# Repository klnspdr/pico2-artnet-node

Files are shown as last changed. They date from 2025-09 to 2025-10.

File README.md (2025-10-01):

# pico2-artnet-node

## Upload to JLCPCB
To generate files for uploading to JLCPCB, the plugin ["Fabrication Toolkit"](https://github.com/bennymeg/Fabrication-Toolkit) is used. It generates Gerber and BOM/Pick'n'Places files. Upload the `.zip` in `production/` as the Gerber file and in PCBA upload `bom.csv`  and `positions.csv`

## Estimated Price

PCB + SMD Components: 8.146$ / board
Missing Components:
    - 4x XLR Connectors (~1.40€ / piece)
    - 1x WizNet W5500-EVB-PICO2 (~12€ / piece)
    - 1x B0505S (~1.05$ / piece)
    - 1x WIZPoE Module (~8€ / piece)
    - 2x 1x20 2.54mm Pinsocket THT Vertical (~0.15$ / piece)
    - 3x 1x4 2.54mm Pinsocket THT Vertical (~0.05$ / piece)

=> Overall cost per board (without shipping): ~20€ / ~28€ (without/with PoE)

## Possible other features / TODOs
- [x] LED showing powered state
- [x] Pinheader for I2C
- [x] Levelshifter for WS2812 etc driving (maybe with separate power input?)
- [ ] Test points
- [x] Silkscreen
- [ ] Mounting Holes
- [ ] JLC Ordering Number / mounting holes for PCBA

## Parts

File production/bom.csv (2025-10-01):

Designator | Footprint | Quantity | Value | LCSC Part #
C1, C11, C14, C17, C20, C4, C5, C8 | 0603 | 8 | 10u | C19702
C10, C12, C13, C15, C16, C18, C19, C6, C7, C9 | 0603 | 10 | 0.1u | C14663
C2, C3 | 1206 | 2 | 100u | C15008
D1, D2, D3 | SOD-323_L1.7-W1.3-LS2.6-RD-1 | 3 | B0520WS | C7502696
D10, D4, D6, D8 | 0805 | 4 | YELLOW | C2296
D11, D5, D7, D9 | 0805 | 4 | RED | C84256
J1 | USB-C-SMD_YPE-C-6PWTL-10-0108 | 1 | USB_C_Receptacle_PowerOnly_6P | C30167331
R1, R2 | 0603 | 2 | 5.1k
R10, R15, R20, R5 | 0603 | 4 | 120R
R11, R14, R16, R19, R21, R4, R6, R9 | 0603 | 8 | 510R
R12, R13, R17, R18, R22, R3, R7, R8 | 0603 | 8 | 56
U3 | SOT-223-3_TabPin2 | 1 | AMS1117-3.3 | C6186
U5, U6, U7, U8 | SOIC-16_L10.3-W7.5-P1.27-LS10.3-BL | 4 | ISO1410BDWR | C2671027

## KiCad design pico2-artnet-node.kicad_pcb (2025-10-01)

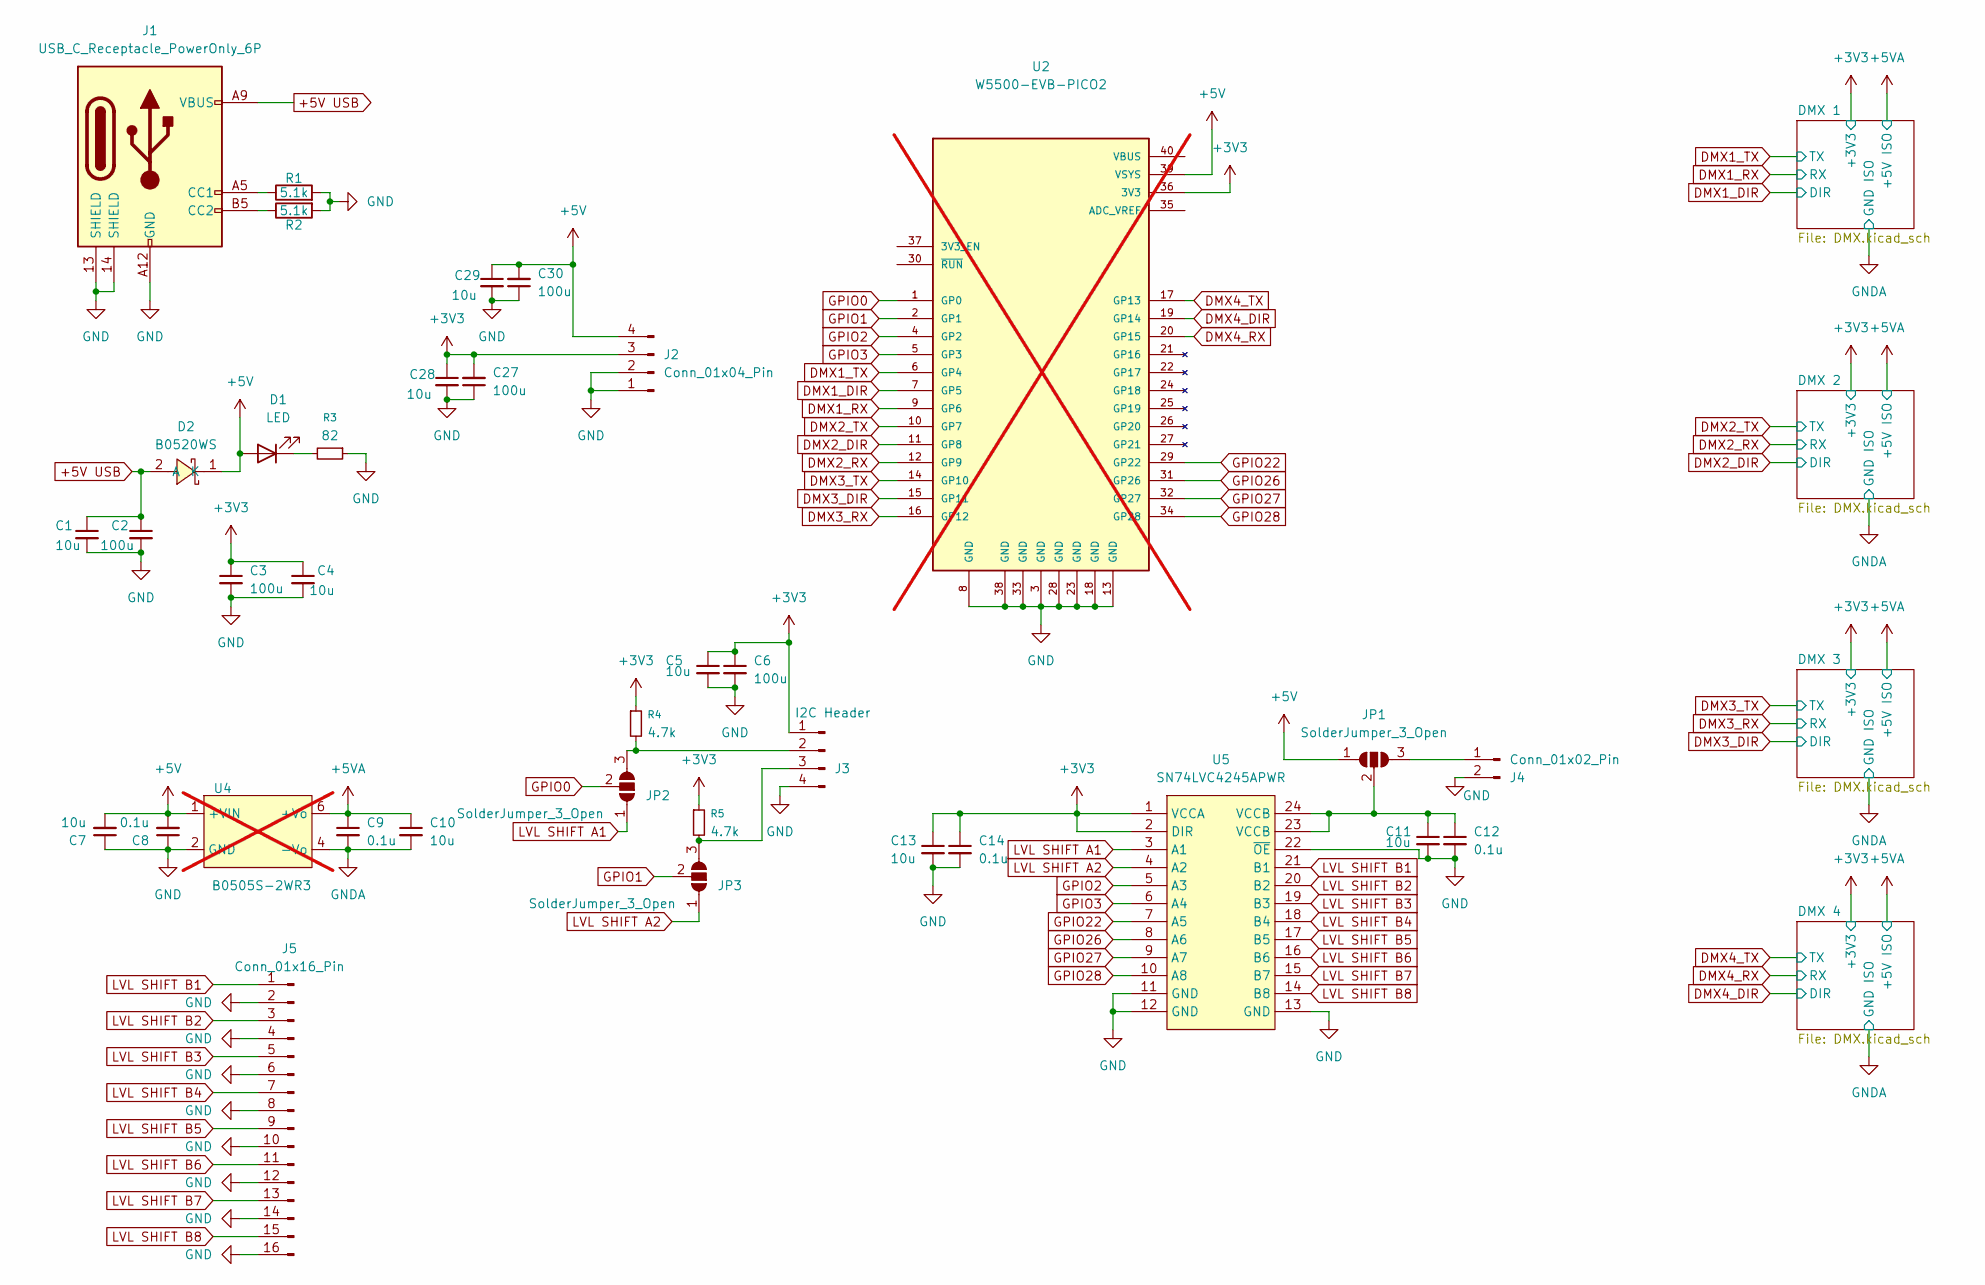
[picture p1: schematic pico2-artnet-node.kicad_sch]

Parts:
C1, C4, C5, C7, C10, C11, C13, C28, C29: 10u; C_0603_1608Metric; LCSC Part C19702
C2, C3, C6, C27, C30: 100u; C_1206_3216Metric; LCSC Part C15008
C8, C9, C12, C14: 0.1u; C_0603_1608Metric; LCSC Part C14663
D1: LED; LED_0805_2012Metric; LCSC Part C2297
D2: B0520WS; SOD-323_L1.7-W1.3-LS2.6-RD-1; LCSC Part C7502696
J1: USB_C_Receptacle_PowerOnly_6P; USB-C-SMD_YPE-C-6PWTL-10-0108_Board-overhang; LCSC Part C30167331
J2: Conn_01x04_Pin; FanPinHeader_1x04_P2.54mm_Vertical
J3: I2C Header; FanPinHeader_1x04_P2.54mm_Vertical
J4: Conn_01x02_Pin; PinSocket_1x02_P2.54mm_Vertical
J5: Conn_01x16_Pin; PinSocket_1x16_P2.54mm_Vertical
JP1, JP2, JP3: SolderJumper_3_Open; PinHeader_1x03_P2.54mm_Vertical
R1, R2: 5.1k; R_0603_1608Metric
R3: 82; R_0603_1608Metric
R4, R5: 4.7k; R_0603_1608Metric
U2: W5500-EVB-PICO2; MODULE_W5500-EVB-PICO2; PARTREV 2022-01-28; not fitted
U4: B0505S-2WR3; PWRM-TH_BXXXXS-2WR3; LCSC Part C5369473; not fitted
U5: SN74LVC4245APWR; TSSOP-24_L7.8-W4.4-P0.65-LS6.4-BL; LCSC Part C7859

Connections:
+3V3: C3.1, C4.1, C5.1, C6.1, C13.1, C14.1, C27.2, C28.1, J2.3, J3.1, R4.1, R5.1, U2.36 (3V3), U5.1 (VCCA), U5.2 (DIR); also elsewhere on the board
+5V: C7.2, C8.2, C29.1, C30.2, D1.2 (A), D2.1 (K), J2.4, JP1.1 (A), U2.39 (VSYS), U4.1 (+VIN)
+5V USB: C1.1, C2.1, D2.2 (A), J1.A9 (VBUS), J1.B9 (VBUS)
+5VA: C9.1, C10.1, U4.6 (+Vo); also elsewhere on the board
DMX1_DIR: U2.7 (GP5); also elsewhere on the board
DMX1_RX: U2.9 (GP6); also elsewhere on the board
DMX1_TX: U2.6 (GP4); also elsewhere on the board
DMX2_DIR: U2.11 (GP8); also elsewhere on the board
DMX2_RX: U2.12 (GP9); also elsewhere on the board
DMX2_TX: U2.10 (GP7); also elsewhere on the board
DMX3_DIR: U2.15 (GP11); also elsewhere on the board
DMX3_RX: U2.16 (GP12); also elsewhere on the board
DMX3_TX: U2.14 (GP10); also elsewhere on the board
DMX4_DIR: U2.19 (GP14); also elsewhere on the board
DMX4_RX: U2.20 (GP15); also elsewhere on the board
DMX4_TX: U2.17 (GP13); also elsewhere on the board
GND: C1.2, C2.2, C3.2, C4.2, C5.2, C6.2, C7.1, C8.1, C11.2, C12.2, C13.2, C14.2, C27.1, C28.2, C29.2, C30.1, J1.13 (SHIELD), J1.14 (SHIELD), J1.A12 (GND), J1.B12 (GND), J2.1, J2.2, J3.4, J4.2, J5.2, J5.4, J5.6, J5.8, J5.10, J5.12, J5.14, J5.16, R1.2, R2.2, R3.1, U2.3 (GND), U2.8 (GND), U2.13 (GND), U2.18 (GND), U2.23 (GND), U2.28 (GND), U2.33 (GND), U2.38 (GND), U4.2 (GND), U5.11 (GND), U5.12 (GND), U5.13 (GND), U5.22 (~OE); also elsewhere on the board
GNDA: C9.2, C10.2, U4.4 (-Vo); also elsewhere on the board
GPIO0: JP2.2 (C), U2.1 (GP0)
GPIO1: JP3.2 (C), U2.2 (GP1)
GPIO2: U2.4 (GP2), U5.5 (A3)
GPIO3: U2.5 (GP3), U5.6 (A4)
GPIO22: U2.29 (GP22), U5.7 (A5)
GPIO26: U2.31 (GP26), U5.8 (A6)
GPIO27: U2.32 (GP27), U5.9 (A7)
GPIO28: U2.34 (GP28), U5.10 (A8)
LVL SHIFT A1: JP2.1 (A), U5.3 (A1)
LVL SHIFT A2: JP3.1 (A), U5.4 (A2)
LVL SHIFT B1: J5.1, U5.21 (B1)
LVL SHIFT B2: J5.3, U5.20 (B2)
LVL SHIFT B3: J5.5, U5.19 (B3)
LVL SHIFT B4: J5.7, U5.18 (B4)
LVL SHIFT B5: J5.9, U5.17 (B5)
LVL SHIFT B6: J5.11, U5.16 (B6)
LVL SHIFT B7: J5.13, U5.15 (B7)
LVL SHIFT B8: J5.15, U5.14 (B8)
unnamed: D1.1 (K), R3.2
unnamed: J1.A5 (CC1), R1.1
unnamed: J1.B5 (CC2), R2.1
unnamed: J3.2, JP2.3 (B), R4.2
unnamed: J3.3, JP3.3 (B), R5.2
unnamed: J4.1, JP1.3 (B)
unnamed: C11.1, C12.1, JP1.2 (C), U5.23 (VCCB), U5.24 (VCCB)

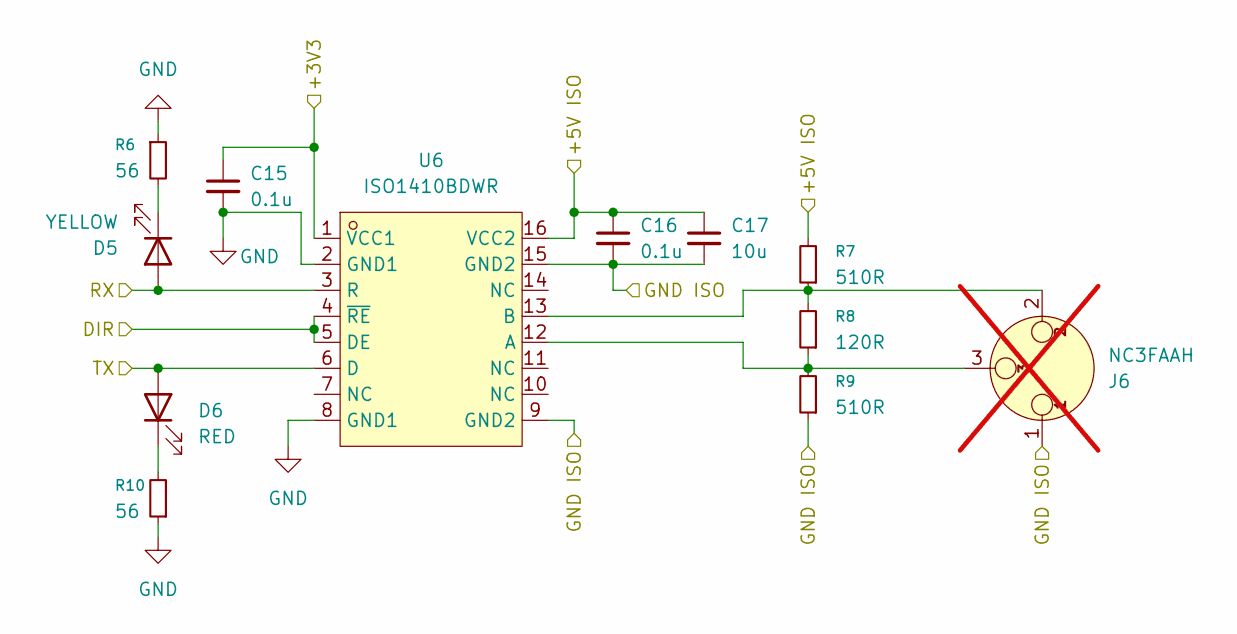
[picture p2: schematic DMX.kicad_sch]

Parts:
C15, C16: 0.1u; C_0603_1608Metric; LCSC Part C14663
C17: 10u; C_0603_1608Metric; LCSC Part C19702
D5: YELLOW; LED_0805_2012Metric; LCSC Part C2296
D6: RED; LED_0805_2012Metric; LCSC Part C84256
J6: NC3FAAH; Jack_XLR_Neutrik_NC3FAAH_Horizontal_Board-Overhang; LCSC Part C368521; not fitted
R6, R10: 56; R_0603_1608Metric
R7, R9: 510R; R_0603_1608Metric
R8: 120R; R_0603_1608Metric
U6: ISO1410BDWR; SOIC-16_L10.3-W7.5-P1.27-LS10.3-BL; LCSC Part C2671027

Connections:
+3V3: C15.1, U6.1 (VCC1); also elsewhere on the board
+5VA: C16.1, C17.1, R7.2, U6.16 (VCC2); also elsewhere on the board
DMX1_DIR: U6.4 (~RE), U6.5 (DE); also elsewhere on the board
DMX1_RX: D5.2 (A), U6.3 (R); also elsewhere on the board
DMX1_TX: D6.2 (A), U6.6 (D); also elsewhere on the board
GND: C15.2, R6.1, R10.1, U6.2 (GND1), U6.8 (GND1); also elsewhere on the board
GNDA: C16.2, C17.2, J6.1, R9.1, U6.9 (GND2), U6.15 (GND2); also elsewhere on the board
unnamed: D5.1 (K), R6.2
unnamed: D6.1 (K), R10.2
unnamed: J6.3, R8.1, R9.2, U6.12 (A)
unnamed: J6.2, R7.1, R8.2, U6.13 (B)

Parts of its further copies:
C18, C19, C21, C22, C24, C25: 0.1u; C_0603_1608Metric; LCSC Part C14663
C20, C23, C26: 10u; C_0603_1608Metric; LCSC Part C19702
D7, D9, D11: YELLOW; LED_0805_2012Metric; LCSC Part C2296
D8, D10, D12: RED; LED_0805_2012Metric; LCSC Part C84256
J7, J8, J9: NC3FAAH; Jack_XLR_Neutrik_NC3FAAH_Horizontal_Board-Overhang; LCSC Part C368521; not fitted
R11, R15, R16, R20, R21, R25: 56; R_0603_1608Metric
R12, R14, R17, R19, R22, R24: 510R; R_0603_1608Metric
R13, R18, R23: 120R; R_0603_1608Metric
U7, U8, U9: ISO1410BDWR; SOIC-16_L10.3-W7.5-P1.27-LS10.3-BL; LCSC Part C2671027

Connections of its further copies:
+3V3: C18.1, C21.1, C24.1, U7.1 (VCC1), U8.1 (VCC1), U9.1 (VCC1); also elsewhere on the board
+5VA: C19.1, C20.1, C22.1, C23.1, C25.1, C26.1, R12.2, R17.2, R22.2, U7.16 (VCC2), U8.16 (VCC2), U9.16 (VCC2); also elsewhere on the board
DMX2_DIR: U7.4 (~RE), U7.5 (DE); also elsewhere on the board
DMX2_RX: D7.2 (A), U7.3 (R); also elsewhere on the board
DMX2_TX: D8.2 (A), U7.6 (D); also elsewhere on the board
DMX3_DIR: U8.4 (~RE), U8.5 (DE); also elsewhere on the board
DMX3_RX: D9.2 (A), U8.3 (R); also elsewhere on the board
DMX3_TX: D10.2 (A), U8.6 (D); also elsewhere on the board
DMX4_DIR: U9.4 (~RE), U9.5 (DE); also elsewhere on the board
DMX4_RX: D11.2 (A), U9.3 (R); also elsewhere on the board
DMX4_TX: D12.2 (A), U9.6 (D); also elsewhere on the board
GND: C18.2, C21.2, C24.2, R11.1, R15.1, R16.1, R20.1, R21.1, R25.1, U7.2 (GND1), U7.8 (GND1), U8.2 (GND1), U8.8 (GND1), U9.2 (GND1), U9.8 (GND1); also elsewhere on the board
GNDA: C19.2, C20.2, C22.2, C23.2, C25.2, C26.2, J7.1, J8.1, J9.1, R14.1, R19.1, R24.1, U7.9 (GND2), U7.15 (GND2), U8.9 (GND2), U8.15 (GND2), U9.9 (GND2), U9.15 (GND2); also elsewhere on the board
unnamed: D7.1 (K), R11.2
unnamed: D8.1 (K), R15.2
unnamed: D9.1 (K), R16.2
unnamed: D10.1 (K), R20.2
unnamed: D11.1 (K), R21.2
unnamed: D12.1 (K), R25.2
unnamed: J7.3, R13.1, R14.2, U7.12 (A)
unnamed: J7.2, R12.1, R13.2, U7.13 (B)
unnamed: J8.3, R18.1, R19.2, U8.12 (A)
unnamed: J8.2, R17.1, R18.2, U8.13 (B)
unnamed: J9.3, R23.1, R24.2, U9.12 (A)
unnamed: J9.2, R22.1, R23.2, U9.13 (B)

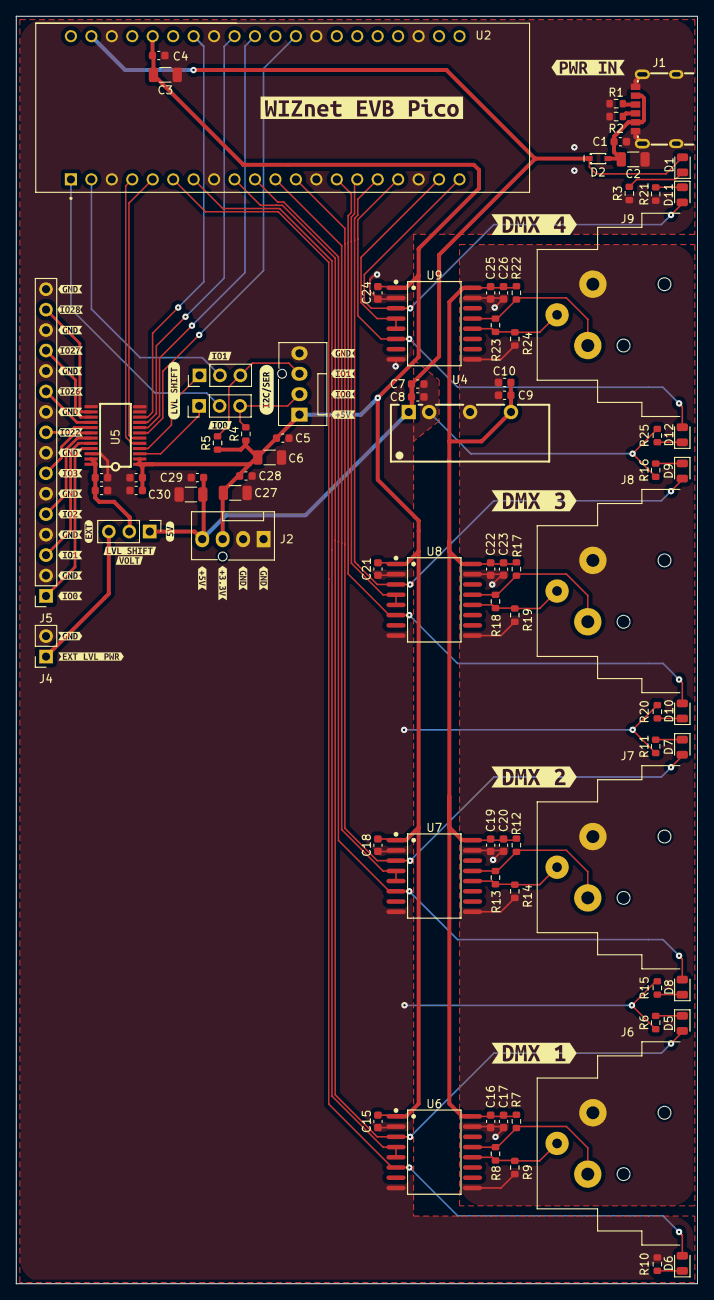
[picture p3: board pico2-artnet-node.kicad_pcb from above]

Board: 2 copper layers, 84.6 x 157.4 mm, 124 parts (0 on the bottom side), 59 nets.

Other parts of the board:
kibuzzard-68DD1E8E: G***; kibuzzard-68DD1E8E
kibuzzard-68DD1E9C: G***; kibuzzard-68DD1E9C
kibuzzard-68DD1EFE: G***; kibuzzard-68DD1EFE
kibuzzard-68DD1F08: G***; kibuzzard-68DD1F08
kibuzzard-68DD1F80: G***; kibuzzard-68DD1F80
kibuzzard-68DD3F78: G***; kibuzzard-68DD3F78
kibuzzard-68DD21E1, kibuzzard-68DD21E1#2, kibuzzard-68DD21E1#3, kibuzzard-68DD21E1#4, kibuzzard-68DD21E1#5, kibuzzard-68DD21E1#6, kibuzzard-68DD21E1#7, kibuzzard-68DD21E1#8: G***; kibuzzard-68DD21E1
kibuzzard-68DD22C2: G***; kibuzzard-68DD22C2
kibuzzard-68DD22D5: G***; kibuzzard-68DD22D5
kibuzzard-68DD22E0: G***; kibuzzard-68DD22E0
kibuzzard-68DD22E9: G***; kibuzzard-68DD22E9
kibuzzard-68DD22F0: G***; kibuzzard-68DD22F0
kibuzzard-68DD23A7: G***; kibuzzard-68DD23A7
kibuzzard-68DD23B6: G***; kibuzzard-68DD23B6
kibuzzard-68DD28CA: G***; kibuzzard-68DD28CA
kibuzzard-68DD43ED, kibuzzard-68DD43ED#2: G***; kibuzzard-68DD43ED
kibuzzard-68DD227C: G***; kibuzzard-68DD227C
kibuzzard-68DD228E: G***; kibuzzard-68DD228E
kibuzzard-68DD244B: G***; kibuzzard-68DD244B
kibuzzard-68DD245B: G***; kibuzzard-68DD245B
kibuzzard-68DD444E: G***; kibuzzard-68DD444E
kibuzzard-68DD501A: G***; kibuzzard-68DD501A
kibuzzard-68DD2296: G***; kibuzzard-68DD2296
kibuzzard-68DD2361: G***; kibuzzard-68DD2361
kibuzzard-68DD2414: G***; kibuzzard-68DD2414
kibuzzard-68DD2461: G***; kibuzzard-68DD2461
kibuzzard-68DD2906: G***; kibuzzard-68DD2906
kibuzzard-68DD2926: G***; kibuzzard-68DD2926
kibuzzard-68DD4448: G***; kibuzzard-68DD4448
kibuzzard-68DD4454, kibuzzard-68DD4454#2: G***; kibuzzard-68DD4454
kibuzzard-68DD5009: G***; kibuzzard-68DD5009

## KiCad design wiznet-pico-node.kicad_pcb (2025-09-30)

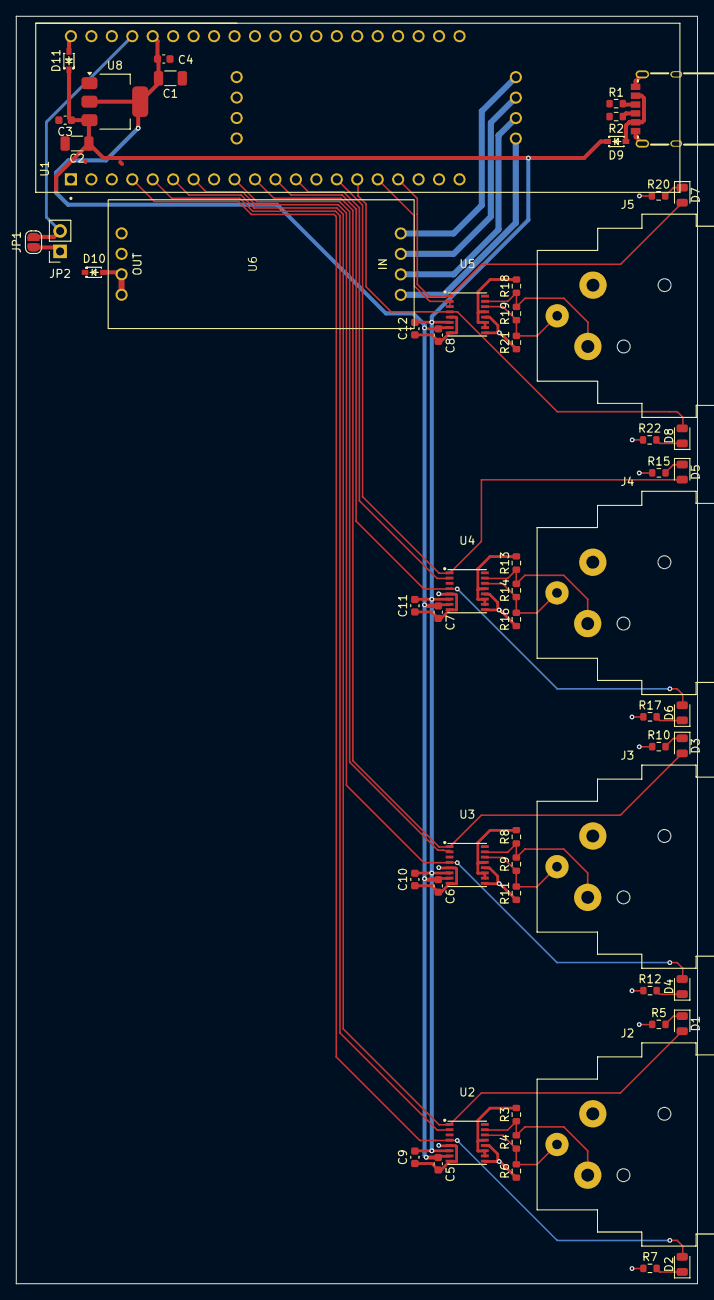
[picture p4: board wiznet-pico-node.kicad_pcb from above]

Board: 2 copper layers, 84.6 x 157.4 mm, 59 parts (0 on the bottom side), 43 nets.

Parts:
C1, C2: 100u; C_1206_3216Metric
C3, C4, C5, C6, C7, C8, C9, C10, C11, C12: 10u; C_0603_1608Metric
D1, D3, D5, D7: YELLOW; LED_0805_2012Metric
D2, D4, D6, D8: RED; LED_0805_2012Metric
D9, D10, D11: B0520WS; SOD-323_L1.7-W1.3-LS2.6-RD-1
J2, J3, J4, J5: NC3FAAH; Jack_XLR_Neutrik_NC3FAAH_Horizontal
J6: USB_C_Receptacle_PowerOnly_6P; USB-C-SMD_YPE-C-6PWTL-10-0108
JP1: disable onboard LDO; SolderJumper-2_P1.3mm_Open_RoundedPad1.0x1.5mm
JP2: disable onboard LDO; PinSocket_1x02_P2.54mm_Vertical
R1, R2: 5.1k; R_0603_1608Metric
R3, R6, R8, R11, R13, R16, R18, R21: 510R; R_0603_1608Metric
R4, R9, R14, R19: 120R; R_0603_1608Metric
R5, R10, R15, R20: 75R; R_0603_1608Metric
R7, R12, R17, R22: 51R; R_0603_1608Metric
U1: W5500-EVB-PICO2; MODULE_W5500-EVB-PICO2
U2, U3, U4, U5: CA-IS2092A; LGA-16_L5.2-W4.7-P0.65-TL_CA-IS2062A-FRANK2
U6: WIZPoE Hat
U8: AMS1117-3.3; SOT-223-3_TabPin2

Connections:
+3V3: C1.1, C4.1, C5.1, C6.1, C7.1, C8.1, U1.36 (3V3), U2.7 (VDDL), U3.7 (VDDL), U4.7 (VDDL), U5.7 (VDDL), U8.2 (VO)
+5V: C2.1, C3.1, C9.1, C10.1, C11.1, C12.1, D9.1 (K), D10.1 (K), D11.1 (K), U2.6 (VDDP), U3.6 (VDDP), U4.6 (VDDP), U5.6 (VDDP), U8.3 (VI)
+5V PoE: D10.2 (A), U6.1 (5V)
+5V RP: D11.2 (A), U1.40 (VBUS)
+5V USB: D9.2 (A), J6.A9 (VBUS), J6.B9 (VBUS)
+5VA: R3.2, R8.2, R13.2, R18.2, U2.10 (VISOIN), U2.11 (VISOOUT), U2.13 (SEL), U3.10 (VISOIN), U3.11 (VISOOUT), U3.13 (SEL), U4.10 (VISOIN), U4.11 (VISOOUT), U4.13 (SEL), U5.10 (VISOIN), U5.11 (VISOOUT), U5.13 (SEL)
AGND: J2.1, J3.1, J4.1, J5.1, R6.1, R11.1, R16.1, R21.1, U2.9 (GND2), U2.12 (GND2), U3.9 (GND2), U3.12 (GND2), U4.9 (GND2), U4.12 (GND2), U5.9 (GND2), U5.12 (GND2)
DMX1_DIR: U1.5 (GP3), U2.2 (~RE), U2.3 (DE)
DMX1_RX: D1.2 (A), U1.6 (GP4), U2.1 (RO)
DMX1_TX: D2.2 (A), U1.4 (GP2), U2.4 (DI)
DMX2_DIR: U1.9 (GP6), U3.2 (~RE), U3.3 (DE)
DMX2_RX: D3.2 (A), U1.10 (GP7), U3.1 (RO)
DMX2_TX: D4.2 (A), U1.7 (GP5), U3.4 (DI)
DMX3_DIR: U1.12 (GP9), U4.2 (~RE), U4.3 (DE)
DMX3_RX: D5.2 (A), U1.14 (GP10), U4.1 (RO)
DMX3_TX: D6.2 (A), U1.11 (GP8), U4.4 (DI)
DMX4_DIR: U1.16 (GP12), U5.2 (~RE), U5.3 (DE)
DMX4_RX: D7.2 (A), U1.17 (GP13), U5.1 (RO)
DMX4_TX: D8.2 (A), U1.15 (GP11), U5.4 (DI)
GND: C1.2, C2.2, C3.2, C4.2, C5.2, C6.2, C7.2, C8.2, C9.2, C10.2, C11.2, C12.2, J6.13 (SHIELD), J6.14 (SHIELD), J6.A12 (GND), J6.B12 (GND), JP1.1 (A), JP2.1 (A), R1.2, R2.2, R5.1, R7.1, R10.1, R12.1, R15.1, R17.1, R20.1, R22.1, U1.3 (GND), U1.8 (GND), U1.13 (GND), U1.18 (GND), U1.23 (GND), U1.28 (GND), U1.33 (GND), U1.38 (GND), U1.42 (GND), U2.5 (GND1), U2.8 (GND1), U3.5 (GND1), U3.8 (GND1), U4.5 (GND1), U4.8 (GND1), U5.5 (GND1), U5.8 (GND1), U6.2 (GND), U8.1 (GND)
unnamed: D1.1 (K), R5.2
unnamed: D2.1 (K), R7.2
unnamed: D3.1 (K), R10.2
unnamed: D4.1 (K), R12.2
unnamed: D5.1 (K), R15.2
unnamed: D6.1 (K), R17.2
unnamed: D7.1 (K), R20.2
unnamed: D8.1 (K), R22.2
unnamed: J6.A5 (CC1), R1.1
unnamed: J6.B5 (CC2), R2.1
unnamed: JP1.2 (B), JP2.2 (B), U1.37 (3V3_EN)
unnamed: U1.43 (VC1+), U6.3 (VC1+)
unnamed: U1.44 (VC1-), U6.4 (VC1-)
unnamed: U1.45 (VC2+), U6.5 (VC2+)
unnamed: U1.46 (VC2-), U6.6 (VC2-)
unnamed: J2.3, R4.1, R6.2, U2.14 (A)
unnamed: J2.2, R3.1, R4.2, U2.15 (B)
unnamed: J3.3, R9.1, R11.2, U3.14 (A)
unnamed: J3.2, R8.1, R9.2, U3.15 (B)
unnamed: J4.3, R14.1, R16.2, U4.14 (A)
unnamed: J4.2, R13.1, R14.2, U4.15 (B)
unnamed: J5.3, R19.1, R21.2, U5.14 (A)
unnamed: J5.2, R18.1, R19.2, U5.15 (B)

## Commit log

2025-09-30 first version, needs changes in DMX circuit
    [DMX.kicad_sch, wiznet-pico-node.kicad_pcb, wiznet-pico-node.kicad_sch]
2025-09-30 add production files
    [bom.csv, designators.csv, positions.csv]
2025-09-30 rename files
    [DMX.kicad_sch, pico2-artnet-node.kicad_pcb, pico2-artnet-node.kicad_sch]
2025-10-01 v0.2 new DMX circuitry
    [DMX.kicad_sch, bom.csv, designators.csv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]
2025-10-01 add levelshifter and silkscreen
    [pico2-artnet-node.kicad_pcb, pico2-artnet-node.kicad_sch]
2025-10-01 change solder jumpers to pins & power break out
    [DMX.kicad_sch, pico2-artnet-node.kicad_pcb, pico2-artnet-node.kicad_sch]
2025-10-01 remove PoE Breakout & rund DRC
    [DMX.kicad_sch, pico2-artnet-node.kicad_pcb, pico2-artnet-node.kicad_sch]
